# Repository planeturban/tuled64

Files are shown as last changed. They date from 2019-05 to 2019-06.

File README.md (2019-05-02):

# Totally Useless LED Programmer 64
### Wuuut?
It's just a useless way to use a RGB led as powerled in a C64. Why? Why not? It's pronounced TÖLP SIXTIFÅR since the author is from Sundsvall, Sweden.

# Hardware
The hardware is pretty much a stripped down Arduno Uno: an ATmega328p, an 16MHz xtal, two capacitors to piggyback on CIA2 of the C64. (The xtal and capacitors could be skipped, runnig at 8Mhz internal clock ought to be enough).

| Part | Footprint | Value |
|--|--|--|
| R1 | 1206 |Value depends on your led |
| R2 | 1206 |Value depends on your led |
| R3 |1206 |Value depends on your led |
| U1 | TQFP32 |ATMega 328P  |
| C1 | 1206 | Capacitor 22pf |
| C2 | 1206 | Capacitor 22pf |
| Y2 | HC49-US | Xtal 16MHz |

## Operation
Int1 (Arduino pin3 or ATmega pin1) is connected to  the port control (/PC) of CIA2, detecting when something is being sent from the C64 by attatching interrupt to falling state. This initializes the sequence counter interrupt function; not a pretty sight in the code, but it works. 

# Software
## 	Protocol
### Data 
| Byte | Data  |
|--|--|
|0-1  | Header: 0xff 0x99 |
| 2 | Data length, CMD + data  |
| 3 | CMD  |
| 4-n | Data, max 27 bytes  |
| n+1 | Checksum 0x100 - ((CMD + data) ^ 0xff) |

**The checksum part:**
CMD plus data is added together, xor'd and substracted from 256, let's say we're setting program speed to 10 (in blink mode: blink every 1 second). We'll be sending, header (0xff 0x99), length (0x02), set speed (0x03), speed itself (0x0a) and checksum (0x100 - ((0x03 + 0x0a) ^ 0xff) ).
| Byte | Data  |
|--|--|
|0|0xff|
|1|0x99|
|2|0x02|
|3|0x03|
|4|0x0a|
|5|0x0e|

### Commands

|Command| CMD |Size | Payload |
|--|--|--|--|
| Set RGB  | 0x01 | 3  | R, G, B value (0-255). Sets max value for all colors. |
| Set Mode | 0x02 | 1 | Mode, see "Mode table" |
| Set Speed | 0x03  | 1 | Speed: 10000 / X millis, used in fade, blink and others.  |
| Program select | 0x04 |1  | Program, 0-31. |
| Program save | 0x05 | 1 | Save to current program.  |
| Set color max | 0x06  | 2 | Color (Red = 0, Green = 1, Blue = 2), value (0-255) |
| Set color min | 0x07  | 2 | Color (Red = 0, Green = 1, Blue = 2), value (0-255) |
| Set program | 0x08  | 8 | Write program, see "Program" |
| Set start up program | 0x09 | 1 | Program number 0-31 |
| Next mode | 0x10 | - |  |
| Previous mode | 0x11  | -  |  |
| Next program | 0x12 | - |  |
| Previous program | 0x13 | - |  |
| Red + 1 | 0x14 | - |  |
| Red - 1 | 0x15 | - |  |
| Green + 1 | 0x16 | - |  |
| Green - 1 | 0x17 | - |  |
| Blue + 1 | 0x18 | - |  |
| Blue - 1 | 0x19 | - |  |
| Red + 10 | 0x1a | - |  |
| Red - 10 | 0x1b | - |  |
| Green + 10 | 0x1c | - |  |
| Green - 10 | 0x1d | - |  |
| Blue + 10 | 0x1e | - |  |
| Blue - 10 | 0x1f | - |  |
| Speed + 1 | 0x20 | - |  |
| Speed - 1 | 0x21 | - |  |
| Speed + 10 | 0x22 | - |  |
| Speed - 10 | 0x23 | - |  |
| Save current program | 0x24 | - |  |
| Write to EEPROM | 0x22 | 2 | Addr, data. |

## Programs

  32 programs are stored in EEPROM: 0-31 * 8 = 256 bytes
| Byte | Data | Explanation |
|--|--|--|
| 0 | Red max |  |
| 1 | Red min |  |
| 2 | Green max |  |
| 3 | Green min |  |
| 4 | Blue max |  |
| 5 | Blue min |  |
| 6 | Mode | |
| 7 | Speed | **10000 / X millis**, used in fade, blink and others. 39 millis is the fastest speed (10000/ 255), 10 seconds is the slowest. | 

## Arduino

### Configuration
#### Modes
When creating a new mode one have to update the maxMode byte and the switch statement in setup() adding a function call to the new mode function. 

A mode function is nothing but a loop that waits for exitLoop to become not zero. exitLoop is set in the interrupt routine if the command sent from the C64 was executed. **Good practice**: don't use *delay()* in  your mode.

modeZero(), just a normal static led. Sets the color and then goes into a loop.

    void modeZero() {
	  analogWrite(9, redMax);
	  analogWrite(10, greenMax);
	  analogWrite(11, blueMax);
	  while ( ! exitLoop ); // wait for next command.
	}

modeOne(), blinking led.

	void modeOne() {
	  unsigned long last = millis();
	  int ledStatus = 0;
	  while ( ! exitLoop ) {
	    if ( millis() - last >= (10000 / speed))  {
	      if ( ledStatus ) {
	        analogWrite(9, 0);
	        analogWrite(10, 0);
	        analogWrite(11, 0);
	        ledStatus = 0;
	      } else {
	        analogWrite(9, redMax);
	        analogWrite(10, greenMax);
	        analogWrite(11, blueMax);
	        ledStatus = 1;
	      }
	      last = millis();
	    }
	  }
	}

### FYI: How data is read.
As described in operetion an interrupt is attached, to read the data. However since there aren't 8 input pins available in a port the full byte sent from the C64 is pieced together using nibbles from PORTD and C. 

	void readData() {
	  value = (PIND & 0xF0) | (PINC & 0x0F); // Add nibbles to a byte.
	  if ( ! sequence && value == 0xff ) {
	    sequence++;
	    data[0] = value;
	  } else if ( sequence == 1 ) {
	    if ( value == 0x99 ) {
		      sequence++;
		      data[1] = value;
		      headerOk = 1;
		} else if ( value = 0xff ) {
	      // Just in case.. We might have gotten an extra 0xff from setting the serial port to output on the C64.
		} else {
		      sequence++;
		}
	  } else if ( sequence == 2 && headerOk ) {
	    sequence++;
	    len = value;
	    bytesLeft = value;
	    data[2] = value;
	    if ( len > 27 ) { // Payload too beaucoup
	      clearData();
	      sequence = 0;
	    }
	  } else if ( bytesLeft && sequence > 2) {
	    data[3 + ((bytesLeft * -1) + len)] = value;
	    bytesLeft--;
	  } else if ( ! bytesLeft && sequence > 2) {
	    checksum = value;
	    data[len + 3] = value;
	    if ( validateChecksum() ) {
			executeCommand();
	    } else {
			// Not a valid command, do nothing.
	    }
	    clearData();
	    sequence = 0;
	  } else { // Catch all.
	    clearData();
	    sequence = 0;
	  }
	}

### EEPROM layout

| Byte | Data | Explanation |
|--|--|--|
| 0-255 | Programs | As described above. |
| 257-508 | Reserved | |
| 509 | Program at start | Which program to run at start? 0-31 |
| 510 | Enable int0 | Enable interrupt on Arduino pin 2. |
| 511 | Version | Not implemented |

## C64
### Basic (yes, BASIC!) code
I'm using dustlayer as IDE so I'm not using row numbers in the example.

Setting speed to 10.

	rem set port to output
	poke 56579, 255 
	rem calculate checksum, 13 ^ 255 as described above.
	let chk = not 13 and 255
	let c = 256 - chk
	rem send header
	poke 56577, 255
	poke 56577, 153
	rem send length
	poke 56577, 2
	rem send command
	poke 56577, 3
	rem send data
	poke 56577, 10
	rem send checksum
	poke 56577, c
	rem port back to input.
	poke 56579, 0

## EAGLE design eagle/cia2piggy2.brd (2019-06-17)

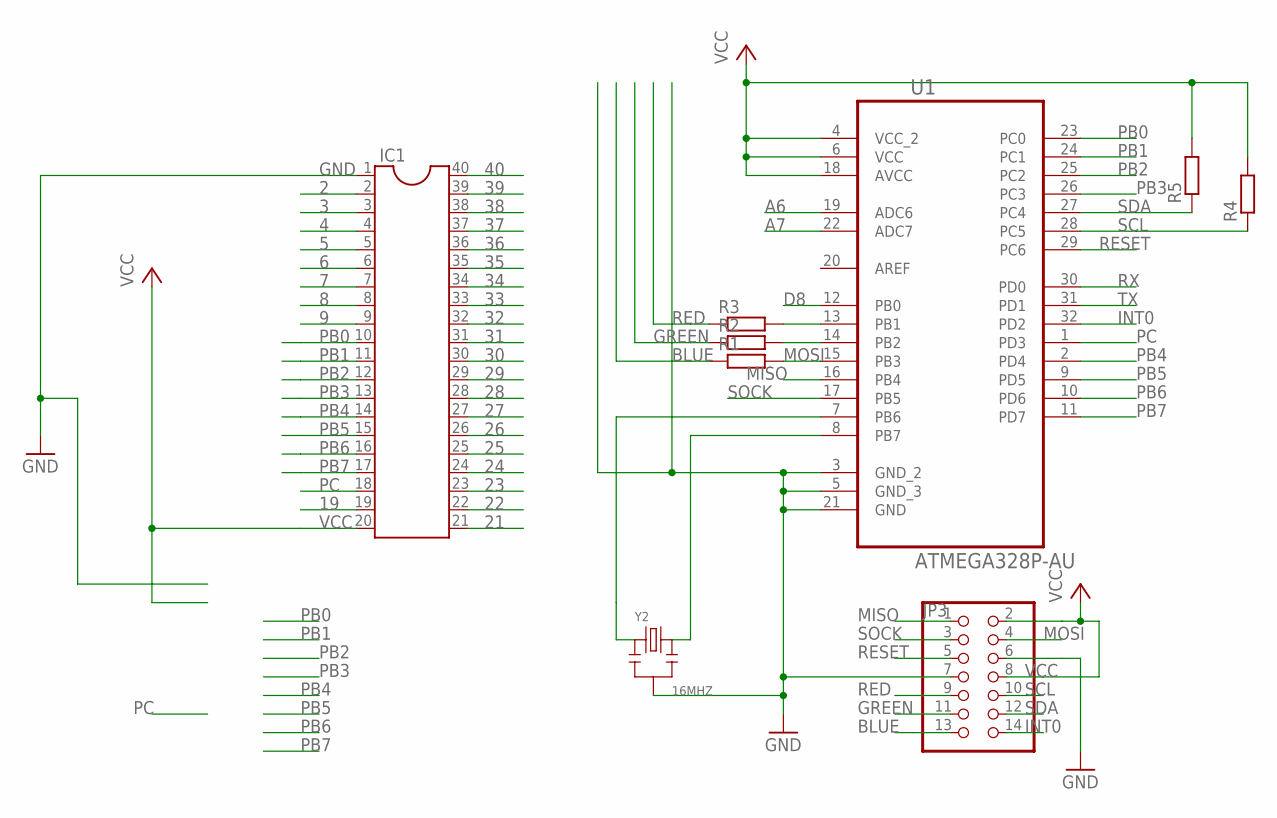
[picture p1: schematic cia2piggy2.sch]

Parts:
IC1: DIL40
JP3: PINHD-2X7; 2X07
R1, R2, R3, R4, R5: R-EU_M0805; M0805
U1: ATMEGA328P-AU; QFP80P900X900X120-32N
Y2: 16MHZ; X3-SMD-3.6X1.3X0.8MM

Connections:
2: IC1.2
3: IC1.3
4: IC1.4
5: IC1.5
6: IC1.6
7: IC1.7
8: IC1.8
9: IC1.9
19: IC1.19
21: IC1.21
22: IC1.22
23: IC1.23
24: IC1.24
25: IC1.25
26: IC1.26
27: IC1.27
28: IC1.28
29: IC1.29
30: IC1.30
31: IC1.31
32: IC1.32
33: IC1.33
34: IC1.34
35: IC1.35
36: IC1.36
37: IC1.37
38: IC1.38
39: IC1.39
40: IC1.40
A6: U1.19 (ADC6)
A7: U1.22 (ADC7)
BLUE: JP3.13, R1.1
D8: U1.12 (PB0)
GND: IC1.1, JP3.6, JP3.7, U1.3 (GND_2), U1.5 (GND_3), U1.21 (GND), Y2.2
GREEN: JP3.11, R2.1
INT0: JP3.14, U1.32 (PD2)
MISO: JP3.1, U1.16 (PB4)
MOSI: JP3.4, R1.2, U1.15 (PB3)
unnamed: R3.2, U1.13 (PB1)
unnamed: R2.2, U1.14 (PB2)
unnamed: U1.7 (PB6), Y2.1
unnamed: U1.8 (PB7), Y2.3
PB0: IC1.10, U1.23 (PC0)
PB1: IC1.11, U1.24 (PC1)
PB2: IC1.12, U1.25 (PC2)
PB3: IC1.13, U1.26 (PC3)
PB4: IC1.14, U1.2 (PD4)
PB5: IC1.15, U1.9 (PD5)
PB6: IC1.16, U1.10 (PD6)
PB7: IC1.17, U1.11 (PD7)
PC: IC1.18, U1.1 (PD3)
RED: JP3.9, R3.1
RESET: JP3.5, U1.29 (PC6)
RX: U1.30 (PD0)
SCL: JP3.10, R4.1, U1.28 (PC5)
SDA: JP3.12, R5.1, U1.27 (PC4)
SOCK: JP3.3, U1.17 (PB5)
TX: U1.31 (PD1)
VCC: IC1.20, JP3.2, JP3.8, R4.2, R5.2, U1.4 (VCC_2), U1.6 (VCC), U1.18 (AVCC)

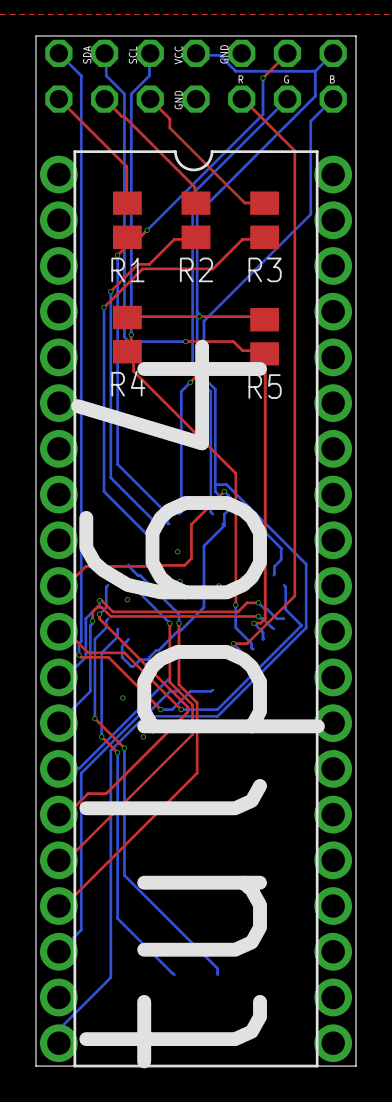
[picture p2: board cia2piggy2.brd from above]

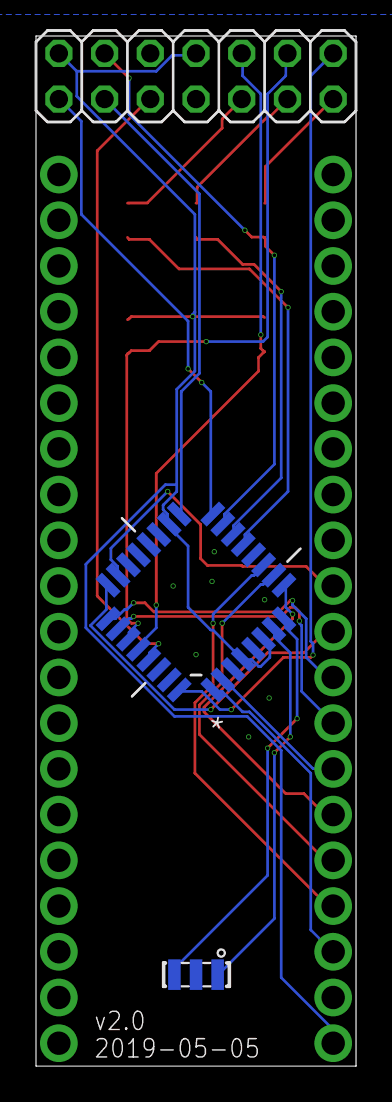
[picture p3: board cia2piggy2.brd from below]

Board: 2 copper layers, 17.8 x 57.2 mm, 9 parts (3 on the bottom side), 25 nets.

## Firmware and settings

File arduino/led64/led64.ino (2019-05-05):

#include <EEPROM.h>

#define DEBUG

/*
   LED64


  Protocol:


  0 - 1 : Header FF99
  2     : Data length, CMD + data
  3 .   : CMD
  4 - n : Data, 27 bytes max.
  n + 1 : Checksum 0x100 - ((CMD + data) ^ 0xff)


  FF  99  01 10 EF
  255 153 01 16 239


  CMDs:
        0x01 - set RGB 3 bytes
        0x02 - set mode 1 byte
             mode:
                   0x00 - static
                   0x01 - blink
                   0x02 - fade
                   0x03 - cycle
        0x03 - set speed 1 byte - 10000 / speed  millis.
        0x04 - set program 1 byte
        0x05 - save to program 1 byte
        0x06 - set color max 2 bytes
               color (red = 0), value
        0x07 - set color min 2 bytes
               color (red = 0), value
        0x08 - set program 8 bytes.

        No data commands.
        0x10 - next mode.
        0x11 - prev mode.
        0x12 - next program.
        0x13 - prev program.
        0x14 - Red + 1
        0x15 - Red - 1
        0x16 - Green + 1
        0x17 - Green - 1
        0x18 - Blue + 1
        0x19 - Blue + 1
        0x1A - Red + 10
        0x1B - Red - 10
        0x1C - Green + 10
        0x1D - Green - 10
        0x1E - Blue + 10
        0x1F - Blue + 10
        0x20 - Speed + 1
        0x21 - Speed - 1
        0x22 - Speed + 10
        0x23 - Speed - 10



        0x24 - save current program.



        0xFF - direct write to EEPROM 2 byte (addr + data)


  32 programs eeprom 0-31 * 8 = 256 bytes in EEPROM
  Program: 8 bytes
    Rmax
    Rmin
    Gmax
    Gmin
    Bmax
    Bmin
    Mode
    Speed


  programData[0] = {255, 0, 255, 0 ,255, 0, 0, 0}

  EEPROM layout:
    0 - 255 : Programs.
    256-511: Config data.



  Config:
  510: enable int0 (pin2). 1 byte



*/



byte value = 0;

volatile byte data[32];
volatile byte sequence = 0;
byte headerOk = 0;
byte len = 0;
byte bytesLeft = 0;

byte program;
byte lastProgram;
byte maxMode = 3;
byte programData[32][8];





volatile byte exitLoop = 0;

volatile unsigned long int0Pressed = 0;



void setup() {
#ifdef DEBUG
  Serial.begin(115200);
  Serial.println("Begin..");
  delay(100);
#endif
  if ( EEPROM.read(510) )
    attachInterrupt(digitalPinToInterrupt(2), restoreButton, FALLING); // Connecteded to PC pin.

  program = EEPROM.read(509);

  lastProgram = 32;

  for ( int i = 1; i < 32; i++ )
    for ( int q = 0; q < 8; q++ )
      programData[i][q] = EEPROM.read((i * 8) + q);

  programData[0][0] = 255;
  programData[0][1] = 0;
  programData[0][2] = 0;
  programData[0][3] = 0;
  programData[0][4] = 0;
  programData[0][5] = 0;
  programData[0][7] = 10;

  if ( program == 255 ) {
    // Blank EEPROM
    program = 0;
    EEPROM.write(509, 0);

    programData[0][6] = 2;
  } else {
    programData[0][6] = 0;
  }


  attachInterrupt(digitalPinToInterrupt(3), readData, FALLING); // Connecteded to PC pin.
  pinMode(9, OUTPUT); // Red
  pinMode(10, OUTPUT); // Green
  pinMode(11, OUTPUT); // Blue



  for ( int cnt = 0; cnt < 6; cnt++ ) {
    analogWrite(9, 255);
    analogWrite(10, 0);
    analogWrite(11, 0);
    delay(50);
    analogWrite(9, 0);
    delay(50);
  }


}

void loop() {
  if ( lastProgram != program ) {
    getProgram();
    lastProgram = program;

  }
  if ( ! programData[program][7] )
    programData[program][7] = 1;
  exitLoop = 0; // Used in the different modes.
  switch (programData[program][6]) {
    case 0:
      modeZero();
      break;
    case 1:
      modeOne();
      break;
    case 2:
      modeRandom();
      break;
    case 3:
      modeRandom2();
      break;

    default:
      // Let's do random blink instead.
#ifdef DEBUG
      Serial.println("Fallback..");
#endif
      programData[program][0] = random(200);
      programData[program][1] = random(200);
      programData[program][2] = random(200);
      programData[program][3] = random(200);
      programData[program][4] = random(200);
      programData[program][5] = random(200);
      programData[program][6] = 1;
      programData[program][7] = 10;
      break;
  }
}

void modeZero() {
#ifdef DEBUG
  Serial.println("Mode zero");
  Serial.println(programData[program][0]);
  Serial.println(program);
#endif
  analogWrite(9, programData[program][0]);
  analogWrite(10, programData[program][2]);
  analogWrite(11, programData[program][4]);
  while ( ! exitLoop ); // wait for next command.
}

void modeOne() {
  // Blink mode
#ifdef DEBUG
  Serial.println("Mode one");
#endif
  unsigned long last = millis();
  int ledStatus = 0;
  while ( ! exitLoop ) {
    if ( millis() - last >= (10000 / programData[program][7]))  {
      if ( ledStatus ) {
        analogWrite(9, 0);
        analogWrite(10, 0);
        analogWrite(11, 0);
        ledStatus = 0;
      } else {
        analogWrite(9, programData[program][0]);
        analogWrite(10, programData[program][2]);
        analogWrite(11, programData[program][4]);
        ledStatus = 1;
      }
      last = millis();
    }
  }
}

void modeRandom() {
  unsigned long last = millis();
  Serial.println("randomMode");
  while ( ! exitLoop ) {
    if ( millis() - last >= (10000 / programData[program][7]))  {
      programData[program][0] = random(200);
      programData[program][1] = random(200);
      programData[program][2] = random(200);
      programData[program][3] = random(200);
      programData[program][4] = random(200);
      programData[program][5] = random(200);
      programData[program][6] = random(2);

      programData[program][7] = random(1, 100);
      last = millis();
      analogWrite(9, programData[program][0]);
      analogWrite(10, programData[program][2]);
      analogWrite(11, programData[program][4]);
    }
  }
  last = millis();
}


void modeRandom2() {
  unsigned long last = millis();
  Serial.println("randomMode");
  while ( ! exitLoop ) {
    if ( millis() - last >= (10000 / programData[program][7]))  {
      programData[program][0] = random(200);
      programData[program][1] = random(200);
      programData[program][2] = random(200);
      programData[program][3] = random(200);
      programData[program][4] = random(200);
      programData[program][5] = random(200);
      programData[program][6] = random(2);

      last = millis();
      analogWrite(9, programData[program][0]);
      analogWrite(10, programData[program][2]);
      analogWrite(11, programData[program][4]);
    }
  }
  last = millis();
}



void fallbackMode() {
#ifdef DEBUG
  Serial.println("Mode fallback");
#endif
  analogWrite(9, 255);
  analogWrite(10, 0);
  analogWrite(11, 0);
  while ( ! exitLoop );
}


void readData() {
  value = (PIND & 0xF0) | (PINC & 0x0F);

#ifdef DEBUG
  Serial.println("PC low!");
  Serial.println(sequence);
  Serial.println(value, BIN);
#endif
  if ( ! sequence && value == 0xff ) {
    sequence++;
    data[0] = value;
#ifdef DEBUG

    Serial.println("Read first header byte ok");
#endif
  } else if ( sequence == 1 ) {
    if ( value == 0x99 ) {
      sequence++;
      data[1] = value;

#ifdef DEBUG
      Serial.println("Read second header byte ok");
#endif
      headerOk = 1;
    } else if ( value = 0xff ) {
      // Just in case..
#ifdef DEBUG
      Serial.println("Got 0xff, skipping sequence stepping.");
#endif
    } else {
      sequence++;
    }
  } else if ( sequence == 2 && headerOk ) {


    sequence++;
    len = value;
    bytesLeft = value;
    data[2] = value;
    if ( len > 27 ) {
      clearData();
      sequence = 0;
    }
#ifdef DEBUG
    Serial.print("Got length: ");
    Serial.println(data[2], DEC);
#endif
  } else if ( bytesLeft && sequence > 2) {
    data[3 + ((bytesLeft * -1) + len)] = value;
    bytesLeft--;
#ifdef DEBUG

    Serial.print("Got value: ");
    Serial.println(value, DEC);
    Serial.print("Bytes left to read: ");
    Serial.println(bytesLeft, DEC);
#endif
  } else if ( ! bytesLeft && sequence > 2) {
    //    checksum = value;
    data[len + 3] = value;
#ifdef DEBUG
    Serial.println("Done reading! Executing!");
#endif
    if ( validateChecksum() ) {
      executeCommand();

    } else {
#ifdef DEBUG
      Serial.println("Command ****NOT**** validated!");
      Serial.println("Data: ");
      Serial.println("0\t1\t2\t3\t4\t5\t6\t7\t8\t9\t10\t11\t12\t13\t14\t15\t16\t17\t18\t19\t20\t21\t22\t23\t24\t25\t26\t27\t28\t29\t30\t31");

      for ( int i = 0; i < 32; i++) {
        Serial.print(data[i]);
        Serial.print("\t");
      }
      Serial.println("");
#endif
    }

    clearData();
    sequence = 0;
  } else {
#ifdef DEBUG

    Serial.println("Clearing data.");
#endif
    clearData();
    sequence = 0;
  }
}

void executeCommand() {
  byte tempVal;
#ifdef DEBUG
  Serial.println("Executing..");
  Serial.println("0\t1\t2\t3\t4\t5\t6\t7\t8\t9\t10\t11\t12\t13\t14\t15\t16\t17\t18\t19\t20\t21\t22\t23\t24\t25\t26\t27\t28\t29\t30\t31");

  for ( int i = 0; i < 32; i++) {
    Serial.print(data[i]);
    Serial.print("\t");
  }
  Serial.println("");
#endif
  switch ( data[3] ) {
    case 0x01:
      // Direct write RGB
      /*     analogWrite(9, data[4]);
           analogWrite(10, data[5]);
           analogWrite(11, data[6]);
      */
      programData[program][0] = data[4];
      programData[program][2] = data[5];
      programData[program][4] = data[6];

      break;

    case 0x02:
      // Set mode
      programData[program][6] = data[4];
      break;
    case 0x03:
      //Set speed
      programData[program][7] = data[4];
      break;
    case 0x04:
      // Select program
      program = data[4];
      break;
    case 0x05:
      // Write to program
      /*     programData[program][0] = redMax;
           programData[program][1] = redMin;
           programData[program][2] = greenMax;
           programData[program][3] = greenMin;
           programData[program][4] = blueMax;
           programData[program][5] = blueMin;
           programData[program][6] = mode;
           programData[program][7] = speed;
      */
#ifdef DEBUG
      EEPROM.put(data[4] * 8, programData[program]);
      Serial.print("Wrote: ");
      for ( int i = 0; i < 8; i++ ) {
        Serial.print(programData[program][i]);
        Serial.print(" ");
      }
      Serial.print(" to program: ");
      Serial.println(data[4]);
#endif
      break;
    case 0x06:
      // Set color max
      switch ( data[4] ) {
        case 0:
          programData[program][0] = data[5];
          break;
        case 1:
          programData[program][2] = data[5];
          break;
        case 2:
          programData[program][4] = data[5];
          break;
      }
      break;
    case 0x07:
      // Set color min
      switch ( data[4] ) {
        case 0:
          programData[program][1] = data[5];
          break;
        case 1:
          programData[program][3] = data[5];
          break;
        case 2:
          programData[program][5] = data[5];
          break;
      }
      break;
    case 0x08:
      programData[program][0] = data[4];
      programData[program][1] = data[5];
      programData[program][2] = data[6];
      programData[program][3] = data[7];
      programData[program][4] = data[8];
      programData[program][5] = data[9];
      programData[program][6] = data[10];
      programData[program][7] = data[11];
      break;

    case 0x09:
      EEPROM.write(509, data[4]);
      break;

    case 0x10:
      // Next mode
      if ( programData[program][6] == maxMode )
        programData[program][6] = 0;
      else
        programData[program][6]++;
      break;

    case 0x11:
      // Previous mode
      if ( !programData[program][6] )
        programData[program][6] = maxMode;
      else
        programData[program][6]--;
      break;

    case 0x12:
      // Next program
      if ( program == 31 )
        program = 0;
      else
        program++;
      break;
    case 0x13:
      // Previous program
      if ( !program )
        program = 31;
      else
        program--;
      break;

    // 0x14 - 0x1F Color increase / descrease 1 or 10 steps.
    case 0x14:
      programData[program][0]++;
      break;

    case 0x15:
      programData[program][0]--;
      break;

    case 0x16:
      programData[program][2]++;
      break;
    case 0x17:
      programData[program][2]--;
      break;
    case 0x18:
      programData[program][4]++;
      break;
    case 0x19:
      programData[program][4]--;
      break;


    case 0x1A:
      if ( programData[program][0] <= 245 )
        programData[program][0] = programData[program][0] + 10;
      else
        programData[program][0] = 255;
      break;

    case 0x1B:
      if ( programData[program][0] >= 10 )
        programData[program][0] = programData[program][0] - 10;
      else
        programData[program][0] = 0;
      break;

    case 0x1C:
      if ( programData[program][2] <= 245 )
        programData[program][2] = programData[program][2] + 10;
      else
        programData[program][2] = 255;
      break;

    case 0x1D:
      if ( programData[program][2] >= 10  )
        programData[program][2] = programData[program][2] - 10;
      else
        programData[program][2] = 0;
      break;

    case 0x1E:
      if ( programData[program][4] <= 245 )
        programData[program][4] = programData[program][4] + 10;
      else
        programData[program][4] = 255;
      break;

    case 0x1F:
      if ( programData[program][4] >= 10 )
        programData[program][4] = programData[program][4] - 10;
      else
        programData[program][4] = 0;
      break;

    case 0x20:
      if ( programData[program][7] < 255 )
        programData[program][7] = programData[program][7]++;
      break;
    case 0x21:
      if ( programData[program][7] )
        programData[program][7] = programData[program][7]--;
      break;

    case 0x22:
      if ( programData[program][7] < 245 )
        programData[program][7] = programData[program][7] + 10;
      break;
    case 0x23:
      if (programData[program][7] > 10 )
        programData[program][7] = programData[program][7] - 10;
      break;

    case 0x24:
      // Save current program.
      /*     programData[program][0] = redMax;
           programData[program][1] = redMin;
           programData[program][2] = greenMax;
           programData[program][3] = greenMin;
           programData[program][4] = blueMax;
           programData[program][5] = blueMin;
           programData[program][6] = mode;
           programData[program][7] = speed;
      */
      EEPROM.put(program * 8, programData[program]);
      break;


    case 0xff:
      EEPROM.write(data[4], data[5]);
      break;


    default:
#ifdef DEBUG
      Serial.println("Unknown command!");
#endif
      break;
  }
#ifdef DEBUG
  Serial.println("End switch");
#endif
  exitLoop = 1;
}




byte validateChecksum() {
  byte temp = 0;
#ifdef DEBUG

  Serial.println("Validating.");
  Serial.print("Incoming checksum: ");
  Serial.println(data[len + 3], DEC);
#endif
  for ( int i = 3; i < len + 3; i++ ) {
    temp = temp + data[i];
#ifdef DEBUG
    Serial.print(i);
    Serial.print(": ");
    Serial.println(data[i], DEC);
#endif
  }
#ifdef DEBUG
  Serial.println(temp, DEC);
  Serial.print("Calculated checksum: ");
  Serial.println((0x100 - (temp ^ 0xff)), DEC);
#endif
  if ( ! (0x100 - (temp ^ 0xff)) - data[len + 3])
    return 1;
  else
    return 0;
}



void clearData() {
  for ( int i = 0; i < 32; i++)
    data[i] = 0;
}

void restoreButton() {

}


void getProgram() {

}

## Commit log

2019-05-02 Arduino code
2019-06-17 Eagle files
    [cia2piggy2.brd, cia2piggy2.sch]
